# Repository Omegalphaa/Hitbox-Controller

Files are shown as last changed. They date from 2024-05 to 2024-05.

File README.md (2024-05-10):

# Hitbox-Controller
2 PCB designs for Hitbox style controllers mint for traditional fighting games.

The Cherry/Gateron design is made to have 30mm circular keycaps for all the buttons execept the left, down, and right buttons they are made for a 24mm buttons. These can be made in whatever preference you may like. 

The Kailh design is made to have a 24mm circular keycaps for all of the buttons execept the up button it was designed for a pill shaped keycap to be accessable to both hands.

Both designs require a Brook UFB and optionally the Brook UFB UP-5 for Playstation 5 support.

In this repository you will be able to find both the Kicad files and the already prepared gerber files to send it to a PCB manufaturer of your choice to get these made.

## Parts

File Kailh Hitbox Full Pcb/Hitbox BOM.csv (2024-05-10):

Comment | Designator | Footprint | JLCPCB Part#
USB connecter | USB1 | HRO-TYPE-C-31-M-12 | C165948
5.1k ohm Resistor | R1, R2 | R_Axial_DIN0204_L3.6mm_D1.6mm_P7.62mm_Horizontal | C2897079
Tactile Switches | SW1, SW2, SW3, SW4, SW5 | SW_PUSH_6mm | C273467

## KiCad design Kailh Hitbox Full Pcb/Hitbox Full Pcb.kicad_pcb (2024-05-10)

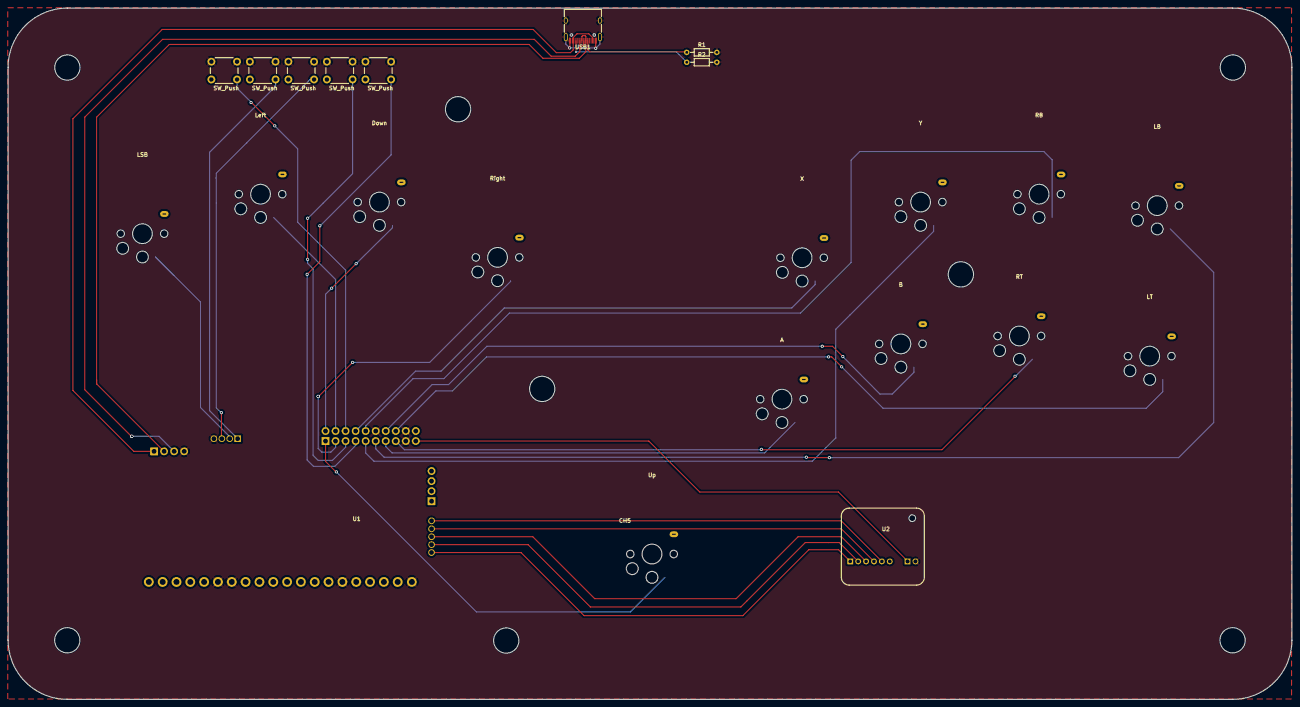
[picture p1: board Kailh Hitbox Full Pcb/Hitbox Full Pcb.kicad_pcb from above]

Board: 2 copper layers, 325.0 x 175.0 mm, 23 parts (0 on the bottom side), 30 nets.

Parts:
CH1, CH2, CH3, CH4, CH5, CH6, CH7, CH8, CH9, CH10, CH11, CH12, CH13: MX-NOLED; ChocV1_V2_Hotswap
R1, R2: 5.1k; R_Axial_DIN0204_L3.6mm_D1.6mm_P7.62mm_Horizontal
SW1, SW2, SW3, SW4, SW5: SW_Push; SW_PUSH_6mm_H8.5mm
U1: brook_ufb; Brook_Universal_Fighting_Board
U2: brook_ufb-up5; UFB-UP5
USB1: HRO-TYPE-C-31-M-12; USB_C_Receptacle_HRO_TYPE-C-31-M-12

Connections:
GND: CH1.1 (COL), CH2.1 (COL), CH3.1 (COL), CH4.1 (COL), CH5.1 (COL), CH6.1 (COL), CH7.1 (COL), CH8.1 (COL), CH9.1 (COL), CH10.1 (COL), CH11.1 (COL), CH12.1 (COL), CH13.1 (COL), R1.2, R2.2, SW1.1, SW2.1, SW3.1, SW4.1, SW5.1, U1.3 (J9_19_GND), U1.4 (J9_20_GND), U1.10 (J9_20_GND), U1.33 (J4_GND), U1.34 (J6-1_GND), U1.38 (J3_GND), U1.43 (J3_GND1), U1.51 (J3_GND2), U1.52 (J3_GND3), U2.1 (J1_2), USB1.13 (Shield), USB1.A1 (GND), USB1.A12 (GND), USB1.B1 (GND), USB1.B12 (GND)
J2-1: U1.29 (J2_1), U2.8 (J3_1)
J2-2: U1.28 (J2_2), U2.7 (J3_2)
J2-3: U1.27 (J2_3), U2.6 (J3_3)
J2-4: U1.26 (J2_4), U2.5 (J3_4)
J2-5: U1.25 (J2_5), U2.4 (J3_5)
LB: CH9.2 (ROW), U1.9 (J9_19_4P/L1/LB)
LSB: CH1.2 (ROW), U1.31 (J4_LSB)
LT: CH13.2 (ROW), U1.6 (J9_20_4K/L2/LT)
unnamed: R1.1, USB1.A5 (CC1)
unnamed: R2.1, USB1.B5 (CC2)
RB: CH8.2 (ROW), U1.12 (J9_20_3P/R1/RB)
RSB: SW3.2, U1.32 (J4_RSB)
RT: CH12.2 (ROW), U1.5 (J9_19_3K/R2/RT)
Touchpad: SW2.2, U1.30 (J4_TPKEY)
VCC: U1.1 (J9_19_VCC), U2.2 (J1_1)
a: CH10.2 (ROW), U1.7 (J9_19_1K/X/A)
b: CH11.2 (ROW), U1.8 (J9_20_2K/O/B)
d+: U1.35 (J6-1_D+), USB1.A6 (DP1), USB1.B6 (DP2)
d-: U1.36 (J6-1_D-), USB1.A7 (DN1), USB1.B7 (DN2)
down: CH3.2 (ROW), U1.20 (J9_20_DOWN)
home: SW1.2, U1.16 (J9_20_Home/Ps/Xb)
left: CH2.2 (ROW), U1.18 (J9_20_LEFT)
option: SW5.2, U1.13 (J9_19_Start/Options)
right: CH4.2 (ROW), U1.17 (J9_19_RIGHT)
share: SW4.2, U1.15 (J9_19_Select/Share/Back)
up: CH5.2 (ROW), U1.19 (J9_19_UP)
v: U1.37 (J6-1_VCC), USB1.A4 (VBUS), USB1.A9 (VBUS), USB1.B4 (VBUS), USB1.B9 (VBUS)
x: CH6.2 (ROW), U1.14 (J9_20_1P/Square/X)
y: CH7.2 (ROW), U1.11 (J9_19_2P/Triangle/Y)

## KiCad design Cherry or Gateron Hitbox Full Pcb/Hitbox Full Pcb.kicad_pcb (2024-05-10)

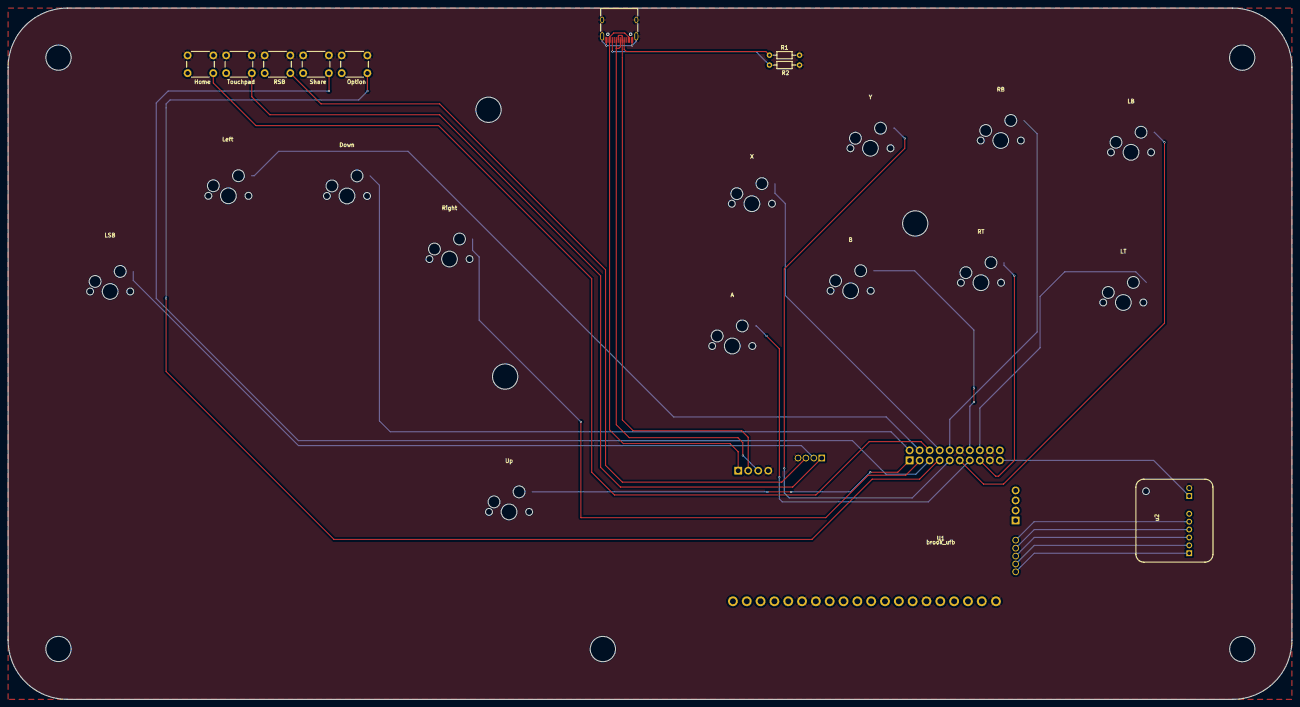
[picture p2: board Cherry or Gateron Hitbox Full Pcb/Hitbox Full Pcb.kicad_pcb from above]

Board: 2 copper layers, 325.0 x 175.0 mm, 23 parts (0 on the bottom side), 30 nets.

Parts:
MX1: LSB; MXOnly-1U-Hotswap
MX2: Left; MXOnly-1U-Hotswap
MX3: Down; MXOnly-1U-Hotswap
MX4: Right; MXOnly-1U-Hotswap
MX5: Up; MXOnly-1U-Hotswap
MX6: X; MXOnly-1U-Hotswap
MX7: Y; MXOnly-1U-Hotswap
MX8: RB; MXOnly-1U-Hotswap
MX9: LB; MXOnly-1U-Hotswap
MX10: A; MXOnly-1U-Hotswap
MX11: B; MXOnly-1U-Hotswap
MX12: RT; MXOnly-1U-Hotswap
MX13: LT; MXOnly-1U-Hotswap
R1, R2: 5.1k; R_Axial_DIN0204_L3.6mm_D1.6mm_P7.62mm_Horizontal
SW1: Home; SW_PUSH_6mm_H8.5mm
SW2: Touchpad; SW_PUSH_6mm_H8.5mm
SW3: RSB; SW_PUSH_6mm_H8.5mm
SW4: Share; SW_PUSH_6mm_H8.5mm
SW5: Option; SW_PUSH_6mm_H8.5mm
U1: brook_ufb; Brook_Universal_Fighting_Board
USB1: HRO-TYPE-C-31-M-12; USB_C_Receptacle_HRO_TYPE-C-31-M-12
u2: brook_ufb-up5; UFB-UP5

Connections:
GND: MX1.1 (COL), MX2.1 (COL), MX3.1 (COL), MX4.1 (COL), MX5.1 (COL), MX6.1 (COL), MX7.1 (COL), MX8.1 (COL), MX9.1 (COL), MX10.1 (COL), MX11.1 (COL), MX12.1 (COL), MX13.1 (COL), R1.2, R2.2, SW1.1, SW2.1, SW3.1, SW4.1, SW5.1, U1.3 (J9_19_GND), U1.4 (J9_20_GND), U1.10 (J9_20_GND), U1.33 (J4_GND), U1.34 (J6-1_GND), U1.38 (J3_GND), U1.43 (J3_GND1), U1.51 (J3_GND2), U1.52 (J3_GND3), USB1.13 (Shield), USB1.A1, USB1.A12 (GND), USB1.B1 (GND), USB1.B12, u2.1 (J1_2)
J2-1: U1.29 (J2_1), u2.8 (J3_1)
J2-2: U1.28 (J2_2), u2.7 (J3_2)
J2-3: U1.27 (J2_3), u2.6 (J3_3)
J2-4: U1.26 (J2_4), u2.5 (J3_4)
J2-5: U1.25 (J2_5), u2.4 (J3_5)
LB: MX9.2 (ROW), U1.9 (J9_19_4P/L1/LB)
LSB: MX1.2 (ROW), U1.31 (J4_LSB)
LT: MX13.2 (ROW), U1.6 (J9_20_4K/L2/LT)
unnamed: R1.1, USB1.A5 (CC1)
unnamed: R2.1, USB1.B5 (CC2)
RB: MX8.2 (ROW), U1.12 (J9_20_3P/R1/RB)
RSB: SW3.2, U1.32 (J4_RSB)
RT: MX12.2 (ROW), U1.5 (J9_19_3K/R2/RT)
Touchpad: SW2.2, U1.30 (J4_TPKEY)
VCC: U1.1 (J9_19_VCC), u2.2 (J1_1)
a: MX10.2 (ROW), U1.7 (J9_19_1K/X/A)
b: MX11.2 (ROW), U1.8 (J9_20_2K/O/B)
d+: U1.35 (J6-1_D+), USB1.A6 (DP1), USB1.B6 (DP2)
d-: U1.36 (J6-1_D-), USB1.A7 (DN1), USB1.B7 (DN2)
down: MX3.2 (ROW), U1.20 (J9_20_DOWN)
home: SW1.2, U1.16 (J9_20_Home/Ps/Xb)
left: MX2.2 (ROW), U1.18 (J9_20_LEFT)
option: SW5.2, U1.13 (J9_19_Start/Options)
right: MX4.2 (ROW), U1.17 (J9_19_RIGHT)
share: SW4.2, U1.15 (J9_19_Select/Share/Back)
up: MX5.2 (ROW), U1.19 (J9_19_UP)
v: U1.37 (J6-1_VCC), USB1.A4 (VBUS), USB1.A9 (VBUS), USB1.B4 (VBUS), USB1.B9 (VBUS)
x: MX6.2 (ROW), U1.14 (J9_20_1P/Square/X)
y: MX7.2 (ROW), U1.11 (J9_19_2P/Triangle/Y)
